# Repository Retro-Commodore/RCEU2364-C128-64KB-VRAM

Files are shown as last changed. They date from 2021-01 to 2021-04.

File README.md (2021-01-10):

# RCEU2364-C128-64KB-VRAM
 64KB VRAM upgrade to the C128/C128D (Not C128DCR as it already has)
 
 See more colors, get higher resolutions, Watch Risen to Oblivion demo as it should be seen.
 
 NOTE: this revision is yet not testet, but should work.

# BOM
 Optional  
 2x 18pin DIL Sockets  
 1x 48pin DIL Socket  
 
 Required  
 2x 24pin DIL Male/Male header (preferably turned)  
 22nF ceramic capacitor  
 2x 4464 or 41464 4bit 64K Ram chips  

# How to place components

Carefully pull out the 80 column graphics chip MOS8563, and insert/solder (highly recommended to use a socket) it into the socket of the vram expansion.  
Insert the vram expansion into the socket where the MOS8563 was sitting.

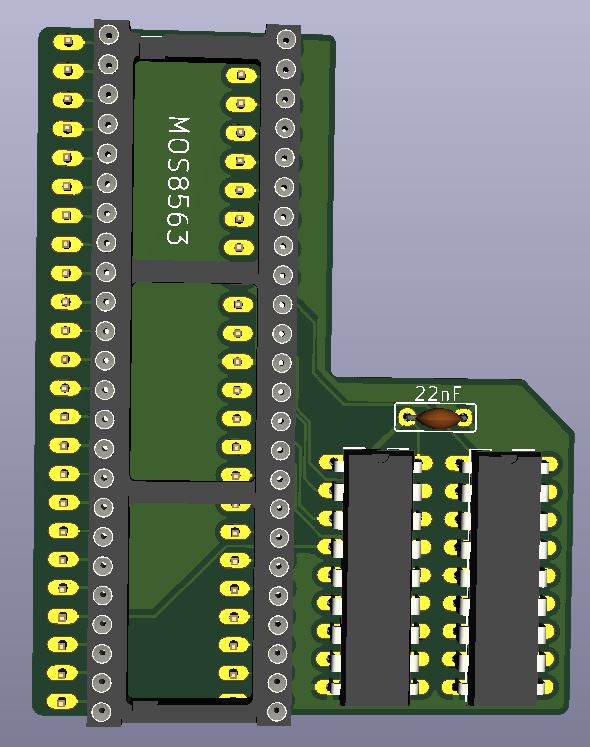
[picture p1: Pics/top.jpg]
TOP


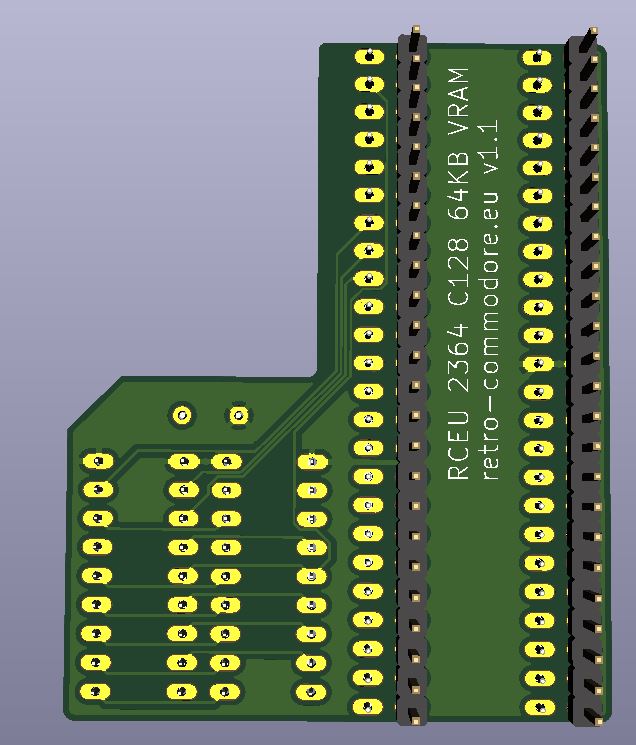
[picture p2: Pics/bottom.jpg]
BOTTOM


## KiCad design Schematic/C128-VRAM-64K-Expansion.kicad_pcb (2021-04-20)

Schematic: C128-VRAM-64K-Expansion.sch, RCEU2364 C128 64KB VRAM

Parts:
C1: 22nF; C5B2.5
IC1: MOS8563
IC2: DIL48
IC3, IC4: 41464C; DIL18

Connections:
/B: IC1.44 (B), IC2.44
/CCLK: IC1.1 (CCLK), IC2.1
/CS: IC1.4 (CS), IC2.4
/D0: IC1.18 (D0), IC2.18
/D1: IC1.17 (D1), IC2.17
/D2: IC1.16 (D2), IC2.16
/D3: IC1.15 (D3), IC2.15
/D4: IC1.14 (D4), IC2.14
/D5: IC1.13 (D5), IC2.13
/D6: IC1.11 (D6), IC2.11
/D7: IC1.10 (D7), IC2.10
/DA0: IC1.26 (DA0), IC2.26, IC3.10 (A7), IC4.10 (A7)
/DA1: IC1.27 (DA1), IC2.27, IC3.8 (A4), IC4.8 (A4)
/DA2: IC1.28 (DA2), IC2.28, IC3.11 (A3), IC4.11 (A3)
/DA3: IC1.29 (DA3), IC2.29, IC3.7 (A5), IC4.7 (A5)
/DA4: IC1.30 (DA4), IC2.30, IC3.12 (A2), IC4.12 (A2)
/DA5: IC1.31 (DA5), IC2.31, IC3.6 (A6), IC4.6 (A6)
/DA6: IC1.32 (DA6), IC2.32, IC3.13 (A1), IC4.13 (A1)
/DA7: IC1.33 (DA7), IC2.33, IC3.14 (A0), IC4.14 (A0)
/DD0: IC1.34 (DD0), IC3.15 (I/O3)
/DD1: IC1.35 (DD1), IC3.3 (I/O2)
/DD2: IC1.36 (DD2), IC3.2 (I/O1)
/DD3: IC1.38 (DD3), IC3.17 (I/O4)
/DD4: IC1.39 (DD4), IC4.15 (I/O3)
/DD5: IC1.40 (DD5), IC4.3 (I/O2)
/DD6: IC1.41 (DD6), IC4.2 (I/O1)
/DD7: IC1.42 (DD7), IC4.17 (I/O4)
/DISPEN: IC1.19 (DISPEN), IC2.19
/DR/~W: IC1.21 (DR/~W), IC2.21, IC3.4 (~WE), IC4.4 (~WE)
/G: IC1.45 (G), IC2.45
/HSYNC: IC1.3 (HSYNC), IC2.3
/I: IC1.43 (I), IC2.43
/INIT: IC1.22 (INIT), IC2.22
/LPEN: IC1.25 (LPEN), IC2.25
/N/C: IC1.6 (N/C), IC2.6
/NC: IC1.5 (NC), IC2.5
/R: IC1.46 (R), IC2.46
/R/~W: IC1.9 (R/~W), IC2.9
/TEST: IC1.24 (TEST), IC2.24
/VSYNC: IC1.20 (VSYNC), IC2.20
/~CAS: IC1.48 (~CAS), IC2.48, IC3.16 (~CAS), IC4.16 (~CAS)
/~CS: IC1.7 (~CS), IC2.7
/~DCLK: IC1.2 (~DCLK), IC2.2
/~RAS: IC1.47 (~RAS), IC2.47, IC3.5 (~RAS), IC4.5 (~RAS)
/~RES: IC1.23 (~RES), IC2.23
/~RS: IC1.8 (~RS), IC2.8
GND: C1.2, IC1.12 (VSS), IC2.12, IC3.1 (~OE), IC3.18 (GND), IC4.1 (~OE), IC4.18 (GND)
VCC: C1.1, IC1.37 (VDD), IC2.37, IC3.9 (VCC), IC4.9 (VCC)

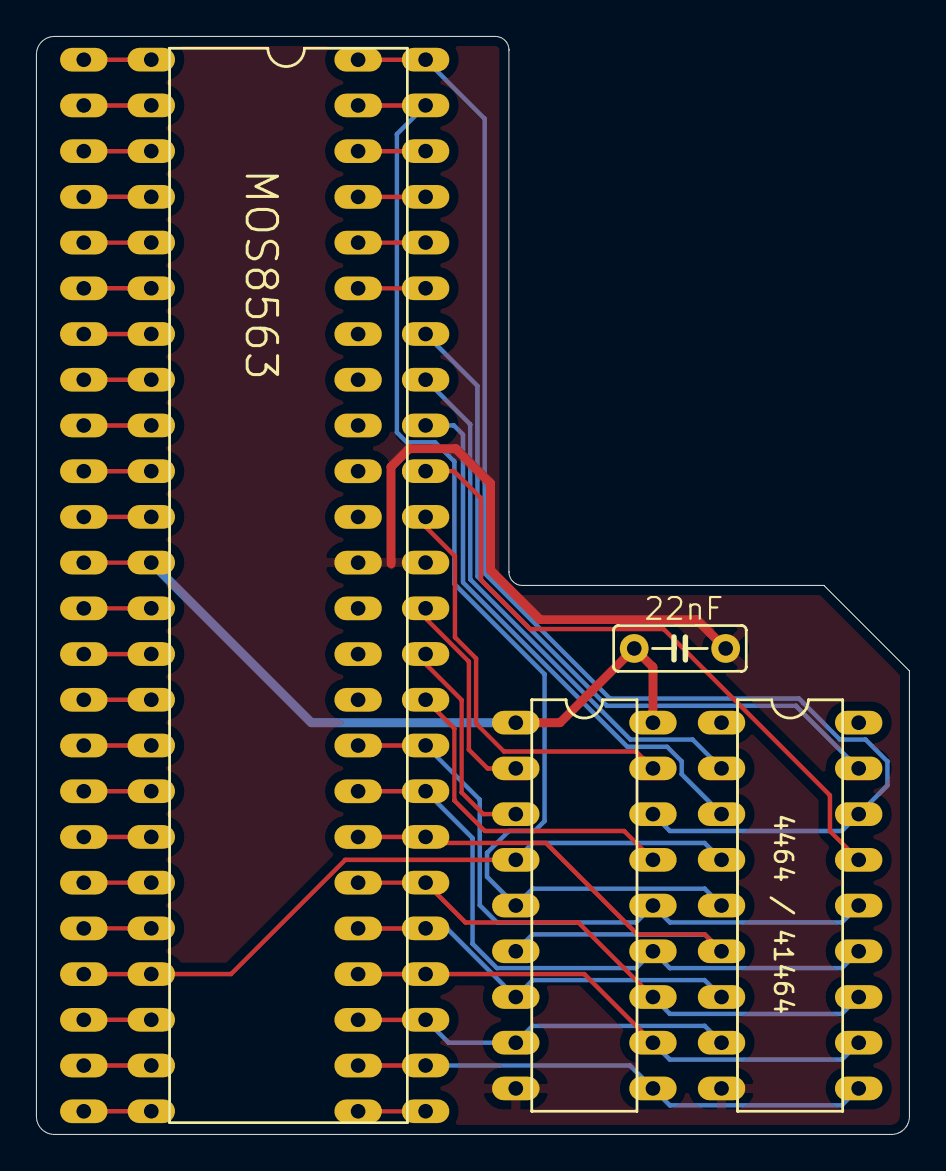
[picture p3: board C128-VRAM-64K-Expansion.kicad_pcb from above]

Board: 2 copper layers, 48.5 x 61.0 mm, 5 parts (0 on the bottom side), 48 nets.

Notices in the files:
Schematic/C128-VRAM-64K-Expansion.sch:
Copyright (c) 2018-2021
